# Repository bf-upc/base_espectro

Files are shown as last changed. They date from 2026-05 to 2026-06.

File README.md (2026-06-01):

# ESPectro 🎮
<p align="center">
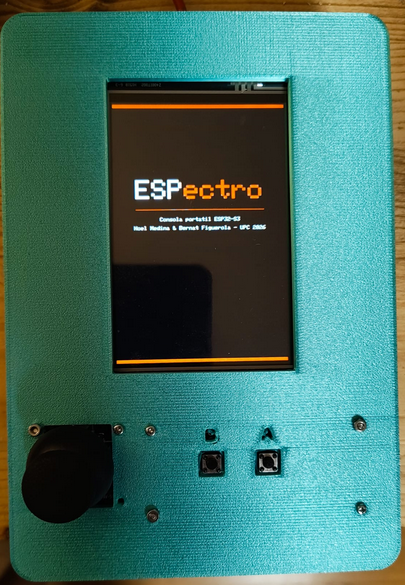
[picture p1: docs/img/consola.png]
  
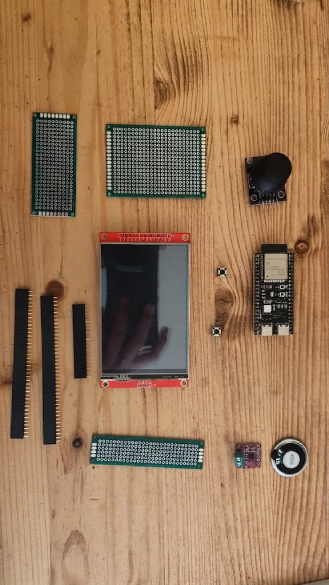
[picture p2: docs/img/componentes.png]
  
</p>

**Consola portátil de videojuegos basada en ESP32-S3**, desarrollada como proyecto final de la asignatura de Processadors Digitals (UPC, 2026).

> Noel Medina & Bernat Figuerola — ESUPC

---

## ¿Qué es ESPectro?

ESPectro es una consola portátil de videojuegos diseñada y construida desde cero. Combina hardware personalizado, firmware en C++ con FreeRTOS, conectividad WiFi, un dashboard web en tiempo real e integración con modelos de lenguaje (LLMs) mediante el protocolo MCP.

El sistema permite cargar nuevos juegos sin cables — directamente desde el navegador vía WiFi.

---

## Hardware

| Componente | Modelo |
|---|---|
| Procesador | ESP32-S3-DevKitC-1 N16R8 |
| Pantalla | TFT ILI9488 4" (SPI) |
| Joystick | HW-504 analógico |
| Audio | MAX98357A I2S + altavoz 8Ω |
| Botones | 2× táctil 6×6mm |
| Carcasa | PLA impreso en 3D — diseño propio |

### Pines de conexión

| GPIO | Función |
|---|---|
| 38 | SPI MOSI (pantalla) |
| 47 | SPI SCLK (pantalla) |
| 48 | SPI MISO (pantalla) |
| 2 | TFT DC |
| 1 | TFT CS |
| 0 | TFT RST |
| 39 | TFT BL |
| 5 | Joystick VRX |
| 4 | Joystick VRY |
| 42 | Joystick SW |
| 40 | Botón A |
| 41 | Botón B |
| 8 | I2S BCLK |
| 16 | I2S LRCLK |
| 18 | I2S DIN |

---

## Arquitectura del software

```
Arranca
  → Splash screen ESPectro
  → Menú principal
        ├─ Botón A → Juego
        └─ Botón B → Game Loader (WiFi)
```

### FreeRTOS — 3 tareas concurrentes

| Tarea | Core | Prioridad | Función |
|---|---|---|---|
| `musicTask` | 0 | 2 | Audio I2S continuo |
| `wifiTask` | 0 | 1 | Servidor web en segundo plano |
| `loop()` | 1 | — | Juego, menú, lógica |

**Sincronización:**
- `audioQueue` — Queue FreeRTOS para efectos de sonido
- `recordMutex` — Mutex para proteger acceso a NVS entre tareas

### WiFi y dashboard

El WiFi arranca automáticamente al encender la consola y se mantiene activo en segundo plano mientras se juega.

- **Red:** `ESPectro` · **Contraseña:** `gameloader`
- **Dashboard:** `http://192.168.4.1`

El dashboard muestra en tiempo real por cada juego:
- Récord máximo
- Número de partidas jugadas
- Media de puntuación
- Gráfica de barras de las últimas 10 partidas

### NVS — Persistencia

Los récords se guardan en la memoria flash no volátil (NVS) y persisten entre reinicios y entre juegos. El historial guarda las últimas 20 partidas por juego.

### Game Loader — OTA vía WiFi

Permite actualizar o cambiar el juego sin cables:

1. Pulsa **Botón B** en el menú
2. Conéctate a la red **ESPectro**
3. Abre `http://192.168.4.1` en el navegador
4. Selecciona el `.bin` y súbelo
5. La consola reinicia con el nuevo juego

### MCP — Integración con LLMs

La consola expone un servidor MCP que permite a los modelos de lenguaje consultar los datos en tiempo real.

| Endpoint | Descripción |
|---|---|
| `GET /mcp/tools` | Lista las tools disponibles |
| `GET /mcp/tools/call?tool=get_records` | Récords e historial |
| `GET /mcp/tools/call?tool=get_status` | Uptime y memoria |
| `GET /mcp/tools/call?tool=get_system_info` | Info del hardware |

---

## Juegos disponibles

| Juego | Repositorio | Descripción |
|---|---|---|
| 🏎 Road Rush | [road_rush_espectro](https://github.com/bf-upc/road_rush_espectro) | Juego de carreras — esquiva obstáculos y acelera con el joystick |
| 🟦 Tetris | [tetris_espectro](https://github.com/bf-upc/tetris_espectro) | Tetris clásico — piezas, líneas y puntuación |
| ♣️ Blackjack | [blackjack_espectro](https://github.com/bf-upc/blackjack_espectro) | Blackjack con baraja de poker y mecánica de apuestas |
| ⭕ Tres en Ratlla | [tres_en_ratlla_ESPectro](https://github.com/nm-upc/tres_en_ratlla_ESPectro) | Tres en raya contra la IA con algoritmo minimax |
| 🐸 Frogger | [frogger_ESPectro](https://github.com/nm-upc/frogger_ESPectro) | Cruza la carretera esquivando coches |
| 🐍 Snake | [snake_ESPectro](https://github.com/nm-upc/snake_ESPectro) | Snake clásico — come manzanas y crece sin chocarte |
| 🐦 Flappy Bird | [flappy_bird_ESPectro](https://github.com/nm-upc/flappy_bird_ESPectro) | Esquiva tuberías pulsando el botón A |
| 💣 Buscaminas | [buscaminas_ESPectro](https://github.com/nm-upc/buscaminas_ESPectro) | Buscaminas clásico con joystick |

---

## Estructura del repositorio

```
base_espectro/
├── README.md
├── PLANTILLA_JUEGOS/
│   ├── src/
│   │   └── main.cpp        ← plantilla para nuevos juegos
│   ├── platformio.ini
│   └── README.md           ← documentación para desarrolladores
├── mcp/
│   ├── mcp_ollama.py       ← puente Ollama ↔ ESPectro
│   ├── start_mcp_bridge.sh ← script linux
│   └── requirements.txt
├── 3D/
│   ├── front.stl           ← carcasa frontal (impresión 3D)
│   └── back.stl            ← carcasa trasera (impresión 3D)
└── docs/
    ├── memoria_tecnica.pdf
    ├── esquema_electrico.png
    └── img/
```

---

## Carcasa 3D

El diseño de la carcasa está disponible en la carpeta [`3D/`](3D/) en formato STL, listo para imprimir.

| Archivo | Descripción |
|---|---|
| `front.stl` | Parte frontal — pantalla, joystick y botones |
| `back.stl` | Parte trasera — ESP32 y altavoz |

**Parámetros de impresión recomendados:**
- Material: PLA
- Relleno: 20%
- Soportes: No necesarios
- Tornillería: M2×25 (unión frontal/trasera), M3×6 (pantalla), M2×6 (joystick)

---

## Crear un nuevo juego

Consulta [`PLANTILLA_JUEGOS/README.md`](PLANTILLA_JUEGOS/README.md) para las instrucciones completas.

Resumen:
1. Copia `PLANTILLA_JUEGOS/src/main.cpp` a tu proyecto
2. Rellena los 4 `TODO` (clave del récord, título, variables, lógica)
3. Compila con PlatformIO
4. Sube el `.bin` vía Game Loader

El juego aparece automáticamente en el dashboard sin ninguna configuración adicional.

---

## Usar el MCP con Ollama

```bash
# Instalar dependencias
pip install -r mcp/requirements.txt

# Instalar modelo necesario
ollama pull llama3.2:3b

# Parar Ollama y reiniciar forzando CPU
pkill ollama
CUDA_VISIBLE_DEVICES="" ollama serve &
sleep 3

# Ejecutar el puente
python3 mcp/mcp_ollama.py
```

Ejemplos de preguntas:
- *"¿Cuál es el récord del Road Rush?"*
- *"¿Cuántas partidas se han jugado en total?"*
- *"¿Cuánto tiempo lleva encendida la consola?"*

---

## Compilar y flashear

Requisitos: **PlatformIO** y la librería `lovyan03/LovyanGFX @ ^1.1.12`.

```bash
# Clonar un juego
git clone https://github.com/bf-upc/road_rush_espectro
cd road_rush_espectro

# Compilar y flashear
pio run --target upload

# Monitor serie
pio device monitor
```

---

## Buses y periféricos

| Bus | Periférico | Función |
|-----|---|---|
| SPI | ILI9488 | Pantalla TFT |
| I2S | MAX98357A | Audio digital |
| ADC | HW-504 | Joystick analógico |

---

## Licencia

MIT — libre para usar, modificar y distribuir.

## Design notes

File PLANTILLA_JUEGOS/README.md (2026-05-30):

# ESPectro — Template de Joc

Template per desenvolupar jocs per a la **consola portàtil ESPectro** basada en ESP32-S3.

---

## Índex

1. [Arquitectura del sistema](#arquitectura-del-sistema)
2. [Requisits](#requisits)
3. [Instruccions per a humans](#instruccions-per-a-humans)
4. [Instruccions per a LLMs](#instruccions-per-a-llms)
5. [API de hardware](#api-de-hardware)
6. [Dashboard i MCP](#dashboard-i-mcp)
7. [Exemple mínim](#exemple-mínim)
8. [Pujar el joc a la consola](#pujar-el-joc-a-la-consola)

---

## Arquitectura del sistema

```
firmware.bin = launcher + joc (tot en un sol fitxer)

Arrenca
  → Splash screen ESPectro (logo + jingle)
  → Menú principal
        │
        ├─ Botó A → runGame()  ← AQUÍ VA EL TEU JOC
        │              │
        │              └─ return → torna al menú
        │
        └─ Botó B → Game Loader (WiFi AP)
                        │
                        ├─ Dashboard amb rècords de tots els jocs
                        ├─ Puja nou .bin via navegador
                        └─ Botó A → torna al menú
```

**FreeRTOS — 3 tasques concurrents:**

| Tasca | Core | Prioritat | Funció |
|---|---|---|---|
| `musicTask` | 0 | 2 | Àudio I2S continu |
| `wifiTask` | 0 | 1 | Servidor web en segon pla |
| `loop()` | 1 | — | Joc, menú, lògica |

**Sincronització:**
- `audioQueue` (Queue) — efectes de so des del joc a `musicTask`
- `recordMutex` (Mutex) — protegeix NVS entre `wifiTask` i `runGame()`

**WiFi sempre actiu** des de l'arrencada — el dashboard és accessible a `http://192.168.4.1` en tot moment, fins i tot mentre jugues.

---

## Requisits

**Hardware:**
- ESP32-S3-DevKitC-1 N16R8
- Pantalla TFT ILI9488 4" (SPI)
- Joystick analògic HW-504
- 2 botons tactils 6×6mm
- Amplificador I2S MAX98357A + altavoz 8Ω

**Software:**
- PlatformIO
- Llibreria LovyanGFX `^1.1.12`

**`platformio.ini` mínim:**
```ini
[env:consola]
platform    = espressif32
board       = rymcu-esp32-s3-devkitc-1
framework   = arduino
monitor_speed = 115200
lib_deps =
    lovyan03/LovyanGFX @ ^1.1.12
```

---

## Instruccions per a humans

### Pas 1 — Copia la template
Copia `template_joc.cpp` al teu projecte PlatformIO com a `src/main.cpp`.

### Pas 2 — Omple els TODO

Cerca les línies marcades amb `// TODO:` al fitxer. Són exactament 4:

#### 2.1 Clau del rècord
```cpp
#define RECORD_KEY "nom_joc"  // TODO: canvia això!
```
Posa el nom del teu joc en minúscules i sense espais. Exemple:
```cpp
#define RECORD_KEY "snake"
```
Aquesta clau s'usa per guardar el rècord a la NVS i apareix automàticament al dashboard.

#### 2.2 Títol del menú
```cpp
const char* linia1 = "NOM";   // TODO: primera línia del títol
const char* linia2 = "JOC";   // TODO: segona línia del títol
```

#### 2.3 Variables globals del joc
```cpp
// TODO: VARIABLES GLOBALS DEL JOC
```

#### 2.4 Lògica del joc dins de `runGame()`
```cpp
void runGame() {
    // TODO: implementa el teu joc aquí
}
```

### Pas 3 — Guarda el rècord correctament
Usa el mutex per protegir l'accés a la NVS:
```cpp
if (xSemaphoreTake(recordMutex, pdMS_TO_TICKS(200)) == pdTRUE) {
    saveRecord(score);  // guarda SEMPRE, no només si és rècord
    xSemaphoreGive(recordMutex);
}
```
`saveRecord()` ja gestiona internament si ha de actualitzar el màxim o no.

### Pas 4 — Compila i puja
```
pio run --target upload
```
O via Game Loader (veure [Pujar el joc a la consola](#pujar-el-joc-a-la-consola)).

---

## Instruccions per a LLMs

> Aquesta secció explica com generar un joc complet per a la consola ESPectro a partir de la template.

### Regles obligatòries

1. **NO modificar** cap secció marcada com `// NO MODIFICAR`. Inclou: configuració de pantalla, pins, WiFi, FreeRTOS, Game Loader, menú principal, `setup()`, `loop()`.

2. **Sempre fer `return`** al final de `runGame()` per tornar al menú. Mai usar `while(true)` sense condició de sortida.

3. **`RECORD_KEY`** ha de ser una string única per joc, en minúscules, sense espais ni caràcters especials. Exemples vàlids: `"snake"`, `"pong"`, `"tetris_v2"`.

4. **No usar `delay()` llargs** dins del bucle de joc. Usar `millis()` per controlar el timing.

5. **La pantalla és de 320×480 píxels**, orientació vertical (portrait), rotació 2. L'origen (0,0) és a la cantonada superior esquerra.

6. **L'àudio és síncron** — `playTone()` bloqueja l'execució. Usar-lo amb moderació o implementar una `musicTask` FreeRTOS separada.

7. **Guardar el rècord sempre** al final de la partida (no només si és millor), protegint amb `recordMutex`:
```cpp
if (xSemaphoreTake(recordMutex, pdMS_TO_TICKS(200)) == pdTRUE) {
    saveRecord(score);
    xSemaphoreGive(recordMutex);
}
```

8. **El joc s'auto-registra al dashboard** — en cridar `saveRecord()` per primera vegada, el joc apareix automàticament al dashboard web sense cap configuració addicional.

### Estructura que ha de tenir `runGame()`

```cpp
void runGame() {
    // 1. Carregar rècord
    int bestScore = loadRecord();

    // 2. Inicialitzar variables del joc
    int score = 0;

    // 3. Dibuixar pantalla inicial
    tft.fillScreen(TFT_BLACK);

    // 4. Bucle principal
    unsigned long lastFrame = millis();
    while (true) {

        // Control de framerate (recomanat 20ms = ~50fps)
        if (millis() - lastFrame < 20) continue;
        lastFrame = millis();

        // 5. Llegir controls
        int rawX = analogRead(JOY_X_PIN);
        int rawY = analogRead(JOY_Y_PIN);
        bool btnA = (digitalRead(BTN_A_PIN) == LOW);

        // 6. Lògica del joc
        // ...

        // 7. Dibuixar
        tft.startWrite();
        // ...
        tft.endWrite();

        // 8. Fi de joc -> guardar rècord i tornar al menú
        if (gameOver) {
            if (xSemaphoreTake(recordMutex, pdMS_TO_TICKS(200)) == pdTRUE) {
                saveRecord(score);
                xSemaphoreGive(recordMutex);
            }
            // Mostrar pantalla game over, esperar botó...
            return;  // <- OBLIGATORI per tornar al menú
        }
    }
}
```

### Bones pràctiques de dibuix

- Usar `tft.startWrite()` / `tft.endWrite()` per agrupar operacions.
- **No fer `fillScreen()` cada frame** — esborrar només les zones que canvien.
- Per esborrar un sprite: `tft.fillRect(x, y, w, h, COLOR_FONS)` a la posició anterior.

### Freqüències musicals (rang recomanat: 200-600Hz)

| Nota | Freqüència |
|---|---|
| A3 | 220.0 Hz  |
| C4 | 261.6 Hz  |
| D4 | 293.7 Hz  |
| E4 | 329.6 Hz  |
| G4 | 392.0 Hz  |
| A4 | 440.0 Hz  |
| C5 | 523.3 Hz  |
| D5 | 587.3 Hz  |

Volum recomanat: `0.07f` música de fons, `0.10f` efectes. Mai superar `0.20f`.

---

## API de hardware

### Pantalla

```cpp
SCREEN_W = 320   // amplada en píxels
SCREEN_H = 480   // alçada en píxels

tft.fillScreen(color);
tft.fillRect(x, y, w, h, color);
tft.drawRect(x, y, w, h, color);
tft.fillCircle(x, y, r, color);
tft.drawLine(x0, y0, x1, y1, color);
tft.drawFastHLine(x, y, w, color);
tft.drawFastVLine(x, y, h, color);

tft.setTextSize(n);          // 1=petit, 2=mitjà, 3=gran, 4=molt gran
tft.setTextColor(color, bg);
tft.setCursor(x, y);
tft.print("text");
tft.printf("valor: %d", n);
int w = tft.textWidth("text");

// Colors predefinits
TFT_BLACK, TFT_WHITE, TFT_RED, TFT_GREEN, TFT_BLUE
TFT_YELLOW, TFT_CYAN, TFT_MAGENTA, TFT_DARKGREY

// Color personalitzat
uint16_t color = tft.color565(r, g, b);  // r,g,b: 0-255

// Agrupar operacions (imprescindible per bon rendiment)
tft.startWrite();
// ...
tft.endWrite();
```

### Controls

```cpp
// Joystick analògic (0-4095, centre ~2048)
int rawX = analogRead(JOY_X_PIN);   // esquerra < 1748 / dreta > 2348
int rawY = analogRead(JOY_Y_PIN);   // amunt < 1748 / avall > 2348
bool joyBtn = (digitalRead(JOY_SW_PIN) == LOW);

// Botons (LOW = premut)
bool btnA = (digitalRead(BTN_A_PIN) == LOW);
bool btnB = (digitalRead(BTN_B_PIN) == LOW);

// Obtenir direcció (-1, 0, 1)
int dirX = (rawX < 1748) ? -1 : (rawX > 2348) ? 1 : 0;
int dirY = (rawY < 1748) ? -1 : (rawY > 2348) ? 1 : 0;
```

### Àudio

```cpp
// To sinusoïdal (síncron — bloqueja l'execució)
playTone(float freq, int durationMs, float volume);

// Silenci
playSilence(int durationMs);

// Exemple
playTone(440.0f, 50, 0.10f);          // La4, 50ms
playTone(261.6f, 100, 0.10f);         // C4
playSilence(20);
playTone(392.0f, 200, 0.12f);         // G4
```

### Rècords (NVS — persisteix entre reinicis i entre jocs)

```cpp
// Guardar rècord — sempre protegir amb mutex
if (xSemaphoreTake(recordMutex, pdMS_TO_TICKS(200)) == pdTRUE) {
    saveRecord(score);   // guarda a l'historial i actualitza el màxim si cal
    xSemaphoreGive(recordMutex);
}

// Llegir rècord màxim
int best = loadRecord();
```

L'historial guarda les **últimes 20 partides** per joc. Apareix automàticament al dashboard web.

---

## Dashboard i MCP

### Dashboard web

Accessible a `http://192.168.4.1` mentre la consola està encesa (WiFi sempre actiu).

Mostra per cada joc:
- Rècord màxim
- Nombre de partides jugades
- Mitjana de puntuació
- Darrera puntuació
- Gràfica de barres de les últimes 10 partides

Els jocs apareixen automàticament quan es guarda el primer rècord. No cal configurar res.

### Endpoints MCP

La consola exposa un servidor MCP per integrar-se amb LLMs (Ollama, etc.):

| Endpoint | Descripció |
|---|---|
| `GET /mcp/tools` | Llista les tools disponibles |
| `GET /mcp/tools/call?tool=get_records` | Rècords i historial de tots els jocs |
| `GET /mcp/tools/call?tool=get_status` | Uptime, memòria lliure, IP, versió |
| `GET /mcp/tools/call?tool=get_system_info` | CPU, flash, PSRAM, SDK |

### Ús amb Ollama

```bash
# Instal·lar dependències
pip install ollama requests

# Aturar Ollama i reiniciar forçant CPU (recomanat amb GPU petita)
pkill ollama
CUDA_VISIBLE_DEVICES="" ollama serve &
sleep 3

# Executar el pont MCP
python3 espectro_mcp.py
```

Exemples de preguntes:
- "Quin és el rècord del Road Rush?"
- "Quantes partides s'han jugat en total?"
- "Quant temps porta encesa la consola?"
- "Quanta memòria lliure té l'ESP32?"

---

## Exemple mínim

```cpp
// Variables globals:
int playerX, playerY, score;

// runGame():
void runGame() {
    int bestScore = loadRecord();
    playerX = SCREEN_W / 2;
    playerY = SCREEN_H / 2;
    score = 0;

    tft.fillScreen(TFT_BLACK);

    unsigned long lastFrame = millis();
    unsigned long lastScore = millis();

    while (true) {
        if (millis() - lastFrame < 20) continue;
        lastFrame = millis();

        if (millis() - lastScore > 1000) {
            lastScore = millis();
            score++;
        }

        int rawX = analogRead(JOY_X_PIN);
        int rawY = analogRead(JOY_Y_PIN);
        int dirX = (rawX < 1748) ? -1 : (rawX > 2348) ? 1 : 0;
        int dirY = (rawY < 1748) ? -1 : (rawY > 2348) ? 1 : 0;

        tft.fillRect(playerX-10, playerY-10, 20, 20, TFT_BLACK);
        playerX = constrain(playerX + dirX * 4, 10, SCREEN_W-10);
        playerY = constrain(playerY + dirY * 4, 10, SCREEN_H-10);

        tft.startWrite();
        tft.fillRect(playerX-10, playerY-10, 20, 20, TFT_GREEN);
        tft.setTextColor(TFT_WHITE, TFT_BLACK);
        tft.setTextSize(2);
        tft.setCursor(10, 10);
        tft.printf("Pts: %d  ", score);
        tft.endWrite();

        if (digitalRead(BTN_B_PIN) == LOW) {
            if (xSemaphoreTake(recordMutex, pdMS_TO_TICKS(200)) == pdTRUE) {
                saveRecord(score);
                xSemaphoreGive(recordMutex);
            }
            return;
        }
    }
}
```

---

## Pujar el joc a la consola

1. Compila: `pio run`
2. El binari és a: `.pio/build/rymcu-esp32-s3-devkitc-1/firmware.bin`
3. Prem el **botó B** al menú per entrar al Game Loader
4. Connecta't a la xarxa WiFi **ESPectro** (contrasenya: **gameloader**)
5. Obre el navegador a **http://192.168.4.1**
6. Selecciona el `firmware.bin` i prem "Pujar joc"
7. La consola reinicia amb el nou joc

---

## Pins de referència

| GPIO | Funció |
|---|---|
| 38 | SPI MOSI (pantalla) |
| 47 | SPI SCLK (pantalla) |
| 48 | SPI MISO (pantalla) |
| 2 | TFT DC |
| 1 | TFT CS |
| 0 | TFT RST |
| 39 | TFT BL (retroil·luminació) |
| 5 | Joystick VRX (eix X) |
| 4 | Joystick VRY (eix Y) |
| 42 | Joystick SW (botó) |
| 40 | Botó A |
| 41 | Botó B |
| 8 | I2S BCLK |
| 16 | I2S LRCLK |
| 18 | I2S DIN |

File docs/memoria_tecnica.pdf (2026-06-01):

ESPectro — Memoria Tecnica | Medina & Figuerola — UPC 2026

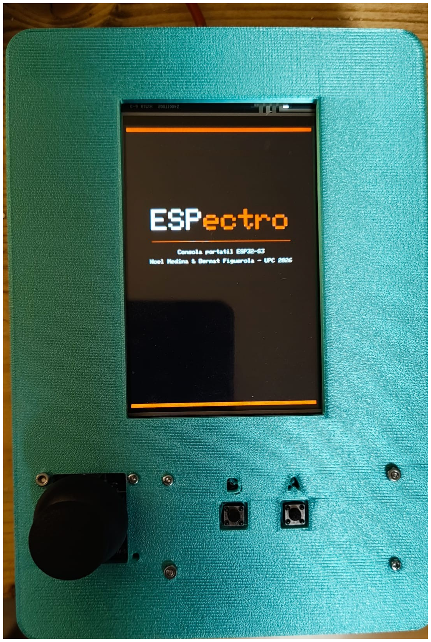
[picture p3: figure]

Processadors Digitals | Pag. 1

# ESPectro

Consola portatil de videojuegos basada en ESP32-S3

## Memoria Tecnica

Noel Medina & Bernat Figuerola Processadors Digitals - ESEIAAT, 2026

## 1. Introduccion

### 1.1 Motivacion

ESPectro nace con el objetivo de disenar y construir una consola portatil de videojuegos completamente funcional utilizando el microcontrolador ESP32-S3 como procesador principal. El proyecto integra hardware personalizado, firmware en tiempo real con FreeRTOS, conectividad WiFi y un sistema de actualizacion de firmware OTA sin necesidad de cables.
A diferencia de las consolas comerciales, ESPectro esta disenada para ser extensible: cualquier desarrollador puede crear nuevos juegos utilizando la template proporcionada y cargarlos en la consola directamente desde el navegador.

### 1.2 Objetivos

- Disenar e implementar una consola portatil con ESP32-S3 como procesador principal.
- Integrar pantalla TFT, joystick analogico, botones y sistema de audio I2S.
- Implementar FreeRTOS con multiples tareas y mecanismos de sincronizacion.
- Desarrollar un sistema de actualizacion OTA via WiFi con interfaz web.
- Implementar un servidor MCP para integracion con modelos de lenguaje (LLMs).
- Disenar e imprimir en 3D una carcasa para la consola.
- Crear una template reutilizable para el desarrollo de nuevos juegos.

## 2. Hardware

### 2.1 Componentes

Componente | Modelo | Interfaz | Funcion
Procesador | ESP32-S3-DevKitC-1 N16R8 | — | CPU principal, WiFi, BLE
Pantalla | TFT ILI9488 4" | SPI | Visualizacion del juego
Joystick | HW-504 analogico | ADC | Control de movimiento
Audio | MAX98357A + altavoz 8 ohm | I2S | Efectos de sonido y musica
Botones | 2x tactil 6x6mm | GPIO | Boton A y Boton B
Carcasa | PLA impreso en 3D | — | Estructura mecanica
Componentes

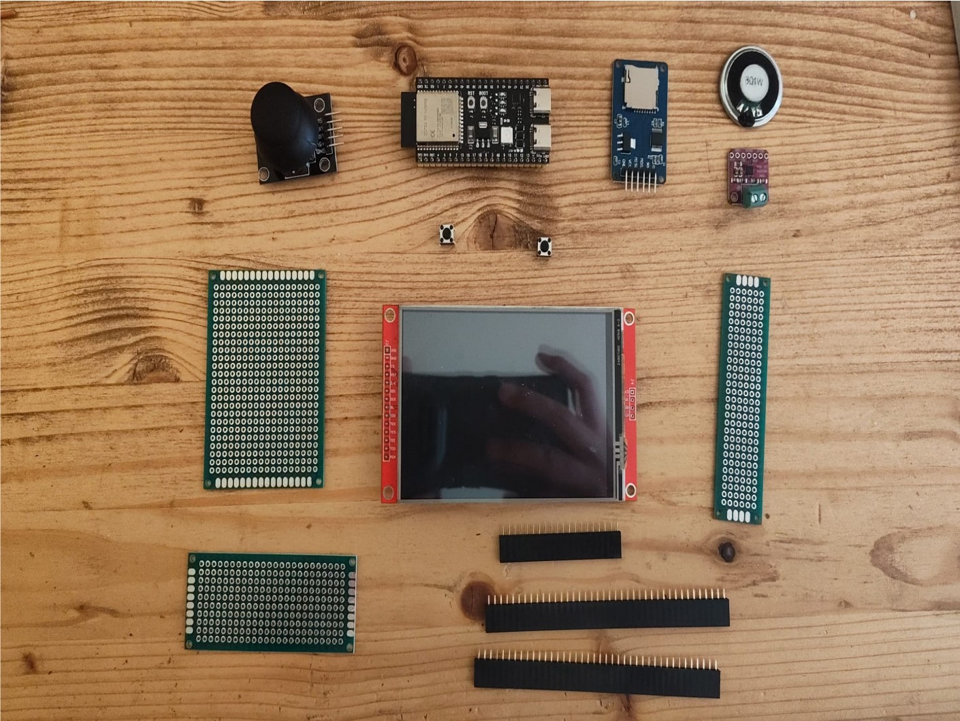
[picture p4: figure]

Inicialmente ibamos a usar un lector de microSD, pero nos llegaron defectuosos y decidimos no usarlo.

### 2.2 Mapa de pines

GPIO | Senal | Bus | Componente
38 | MOSI | SPI | Pantalla ILI9488
47 | SCLK | SPI | Pantalla ILI9488
48 | MISO | SPI | Pantalla ILI9488
2 | DC | SPI | Pantalla ILI9488
1 | CS | SPI | Pantalla ILI9488
0 | RST | GPIO | Pantalla ILI9488
39 | BL | PWM | Retroiluminacion pantalla
5 | VRX | ADC1 | Joystick eje X
4 | VRY | ADC1 | Joystick eje Y
42 | SW | GPIO | Boton joystick
40 | BTN_A | GPIO | Boton A
41 | BTN_B | GPIO | Boton B
8 | BCLK | I2S | MAX98357A
16 | LRCLK | I2S | MAX98357A
18 | DIN | I2S | MAX98357A

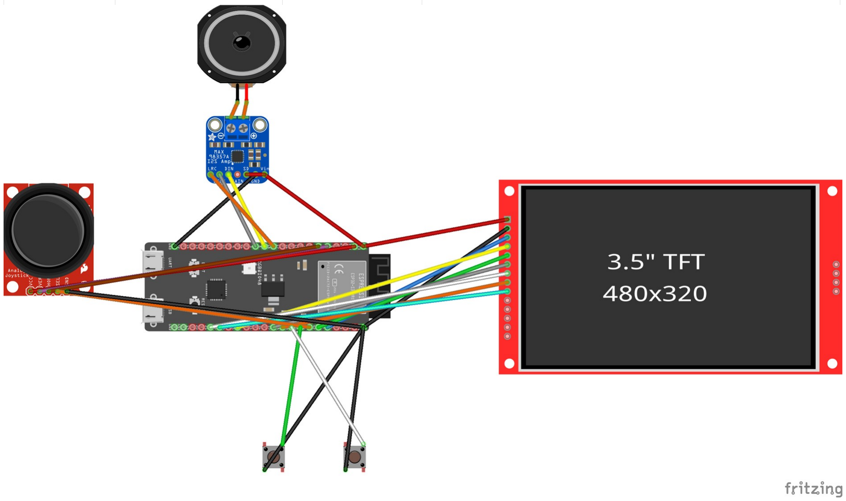
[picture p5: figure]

Diagrama hecho con fritzing

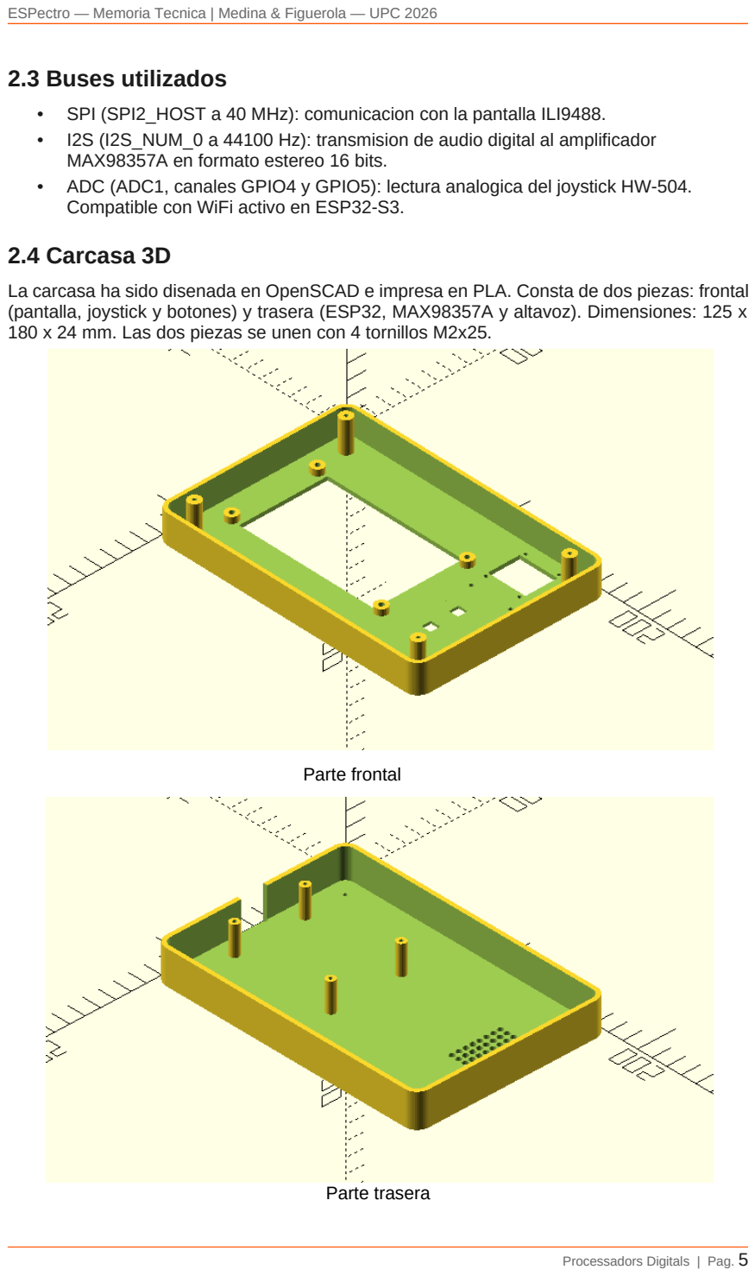
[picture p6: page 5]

### 2.3 Buses utilizados

- SPI (SPI2_HOST a 40 MHz): comunicacion con la pantalla ILI9488.
- I2S (I2S_NUM_0 a 44100 Hz): transmision de audio digital al amplificador MAX98357A en formato estereo 16 bits.
- ADC (ADC1, canales GPIO4 y GPIO5): lectura analogica del joystick HW-504. Compatible con WiFi activo en ESP32-S3.

### 2.4 Carcasa 3D

La carcasa ha sido disenada en OpenSCAD e impresa en PLA. Consta de dos piezas: frontal (pantalla, joystick y botones) y trasera (ESP32, MAX98357A y altavoz). Dimensiones: 125 x 180 x 24 mm. Las dos piezas se unen con 4 tornillos M2x25.

Parte frontal

Parte trasera

## 3. Software

### 3.1 Arquitectura general

El firmware es un binario unico que incluye el launcher y el juego. Al arrancar muestra la splash screen de ESPectro y accede al menu principal, desde donde el usuario puede jugar o acceder al Game Loader para cargar un nuevo juego.

Modulo | Descripcion
Splash screen | Logo ESPectro con jingle musical al arrancar
Menu principal | Muestra el record y las opciones de jugar o cargar
Juego | Logica del juego actual (Road Rush / Tetris)
Game Loader | Servidor web para subir nuevos .bin via WiFi
Dashboard | Estadisticas de todos los juegos en tiempo real
MCP Server | Endpoints para integracion con LLMs via Ollama
NVS | Persistencia de records e historial de partidas

### 3.2 FreeRTOS - Multitarea

Tarea | Core | Prioridad | Funcion
musicTask | 0 | 2 | Reproduce audio I2S de forma continua
wifiTask | 0 | 1 | Gestiona el servidor web en segundo plano
loop() | 1 | — | Logica del juego, menu y controles

Mecanismos de sincronizacion
- audioQueue (Queue): envia eventos de audio desde el juego (core 1) a musicTask (core 0) sin bloquear la ejecucion del juego.
- recordMutex (Mutex): protege el acceso a la NVS entre wifiTask (sirve records al dashboard) y runGame() (escribe records al terminar partida).

### 3.3 WiFi y dashboard

El WiFi arranca en modo Access Point automaticamente al encender la consola. Red: ESPectro, contrasena: gameloader, IP: 192.168.4.1. El dashboard web muestra todos los juegos registrados con su record maximo, numero de partidas, media de puntuacion y grafica de las ultimas 10 partidas. Se actualiza cada 10 segundos.

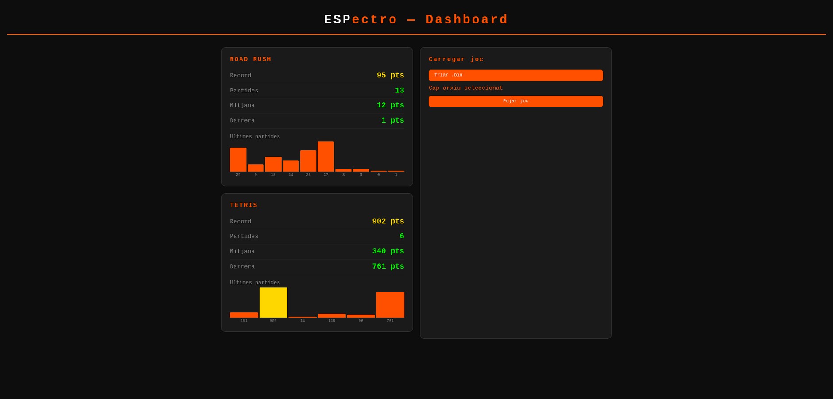
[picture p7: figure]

Dashboard ESPectro

### 3.4 OTA - Game Loader

Permite actualizar el firmware sin cables. El usuario pulsa Boton B, se conecta a la red ESPectro, abre http://192.168.4.1, selecciona el .bin compilado con PlatformIO y lo sube. El ESP32 lo escribe en flash con Update.h y reinicia automaticamente.

### 3.5 Persistencia - NVS

Clave NVS | Tipo | Contenido
road_rush | int32 | Record maximo del juego Road Rush
road_rush_h | string | JSON con las ultimas 20 puntuaciones
game_list | string | CSV con los juegos registrados

### 3.6 Servidor MCP

Endpoint | Descripcion
GET /mcp/tools | Lista las tools disponibles
GET /mcp/tools/call?tool=get_records | Records e historial de todos los juegos
GET /mcp/tools/call?tool=get_status | Uptime, memoria libre, IP y version
GET /mcp/tools/call?tool=get_system_info | CPU, flash, PSRAM y version SDK

Se ha desarrollado un script Python (mcp/mcp_ollama.py) que actua como puente entre Ollama y los endpoints MCP, inyectando los datos de la consola como contexto al modelo de lenguaje.

### 3.7 Template para nuevos juegos

Se ha desarrollado una template (PLANTILLA_JUEGO/src/main.cpp) que integra todo el sistema. Para crear un nuevo juego solo hay que rellenar cuatro secciones TODO: RECORD_KEY, titulo del menu, variables globales y la funcion runGame(). Al guardar el primer record, el juego aparece automaticamente en el dashboard.

## 4. Juegos desarrollados

### 4.1 Road Rush

Juego de carreras en el que el jugador controla un coche que debe esquivar obstaculos. El joystick controla el movimiento lateral y la velocidad. La puntuacion aumenta con cada obstaculo superado. Incluye musica ambient en loop y efectos de sonido via FreeRTOS.

### 4.2 Tetris

Implementacion del Tetris clasico con las siete piezas estandar. El joystick controla el movimiento lateral y la caida rapida. El Boton A rota la pieza. Puntuacion de 100 puntos por linea eliminada con bonus por multiples lineas simultaneas.

### 4.3 Blackjack

Implementación del clásico juego de cartas Blackjack con baraja de póker estándar. El jugador compite contra la banca con el objetivo de acercarse a 21 sin pasarse. El Botón A pide carta (Hit) y el Botón B se planta (Stand). Incluye mecánica de apuestas y gestión de bankroll persistente.

### 4.4 Tres en Ratlla

Implementación del tres en raya contra una inteligencia artificial basada en el algoritmo Minimax, que garantiza el juego óptimo por parte de la máquina. El joystick mueve el cursor por el tablero 3×3 y el Botón A coloca la pieza. La puntuación registra el número de victorias acumuladas.

### 4.5 Frogger

Recreación del arcade clásico Frogger. El jugador controla una rana que debe cruzar una carretera con coches en movimiento. El joystick controla el movimiento en las cuatro direcciones. La puntuación aumenta con cada cruce completado y la dificultad se incrementa progresivamente.

### 4.6 Snake

Implementación del Snake clásico. El jugador controla una serpiente que crece al comer manzanas y debe evitar chocar contra las paredes o contra su propio cuerpo. El joystick controla la dirección. La puntuación aumenta con cada manzana comida.

### 4.7 Flappy Bird

Recreación del popular juego Flappy Bird. El jugador controla un pájaro que debe esquivar tuberías pulsando el Botón A para aletear. La física de gravedad hace que el pájaro caiga continuamente. La puntuación aumenta con cada tubería superada.

### 4.8 Buscaminas

Implementación del Buscaminas clásico con tablero configurable. El joystick mueve el cursor por el tablero y el Botón A revela una casilla. El Botón B marca o desmarca una mina sospechosa con bandera. La puntuación se basa en el tiempo empleado en completar el tablero.

## 5. Resultados

### 5.1 Requisitos cumplidos

Requisito | Estado | Implementacion
ESP32 como procesador | SI | ESP32-S3-DevKitC-1 N16R8
Conectividad WiFi | SI | AP siempre activo (ESPectro)
OTA operativa | SI | HTTP POST con Update.h
Display | SI | TFT ILI9488 4" via SPI
Sensores (ADC/SPI) | SI | Joystick ADC1, pantalla SPI
FreeRTOS 2+ tareas | SI | 3 tareas: music, wifi, loop
Sincronizacion RTOS | SI | Queue + Mutex
2+ buses distintos | SI | SPI + I2S + ADC
PlatformIO reproducible | SI | platformio.ini documentado
MCP (innovacion) | SI | 4 endpoints + puente Ollama

### 5.2 Rendimiento

- Framerate del juego: ~50 fps (frame cada 20 ms en core 1).
- Latencia audio: < 10 ms gracias a la arquitectura de colas FreeRTOS.
- Tiempo de arranque: ~3 segundos hasta el menu principal.
- Tiempo de carga OTA: ~30 segundos para un firmware de 1.2 MB.
- Memoria heap libre en juego: ~120 KB de los 320 KB disponibles.

## 6. Conclusiones

### 6.1 Logros

El proyecto ESPectro ha cumplido todos los requisitos tecnicos de la asignatura e incorpora elementos innovadores como el servidor MCP y la integracion con modelos de lenguaje. La arquitectura modular basada en la template permite extender el sistema con nuevos juegos de forma sencilla, lo que ha quedado demostrado con el desarrollo de dos juegos completamente funcionales.

### 6.2 Dificultades encontradas

- Compatibilidad entre LovyanGFX y algunos headers de ESP-IDF: resuelto usando nvs_flash.h directamente.
- Módulo de microSD defectuoso / tarjetas microSD defectuosas; descartamos el uso del módulo.
- Inestabilidad de la pantalla en el arranque sin reset hardware: resuelto conectando RST al GPIO0.
- Saturacion del audio con playTone() sincrono: resuelto mediante cola FreeRTOS (audioQueue).
- Limitaciones de VRAM de la GPU en el PC para Ollama: resuelto forzando ejecucion en CPU.

### 6.3 Trabajo futuro

- Anadir autenticacion al Game Loader para mayor seguridad.
- Soporte para multiples usuarios en el dashboard.
- Ampliar el servidor MCP con una tool de control remoto del juego.
- Publicar la template como libreria PlatformIO.

## 7. Referencias

- Espressif Systems. ESP32-S3 Technical Reference Manual. https://www.espressif.com
- LovyanGFX. Documentacion oficial. https://github.com/lovyan03/LovyanGFX
- Anthropic. Model Context Protocol (MCP). https://modelcontextprotocol.io
- FreeRTOS. Reference Manual. https://www.freertos.org
- PlatformIO. Documentacion ESP32. https://docs.platformio.org
- Ollama. Documentacion oficial. https://ollama.com

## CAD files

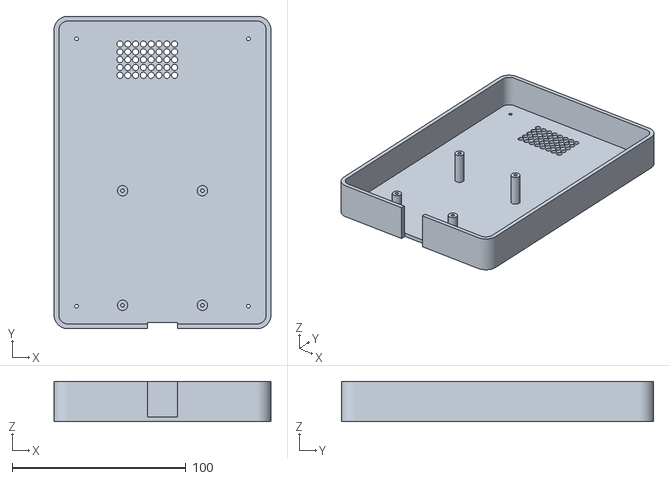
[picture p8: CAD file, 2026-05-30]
3D/back.stl
125.0 x 180.0 x 23.1

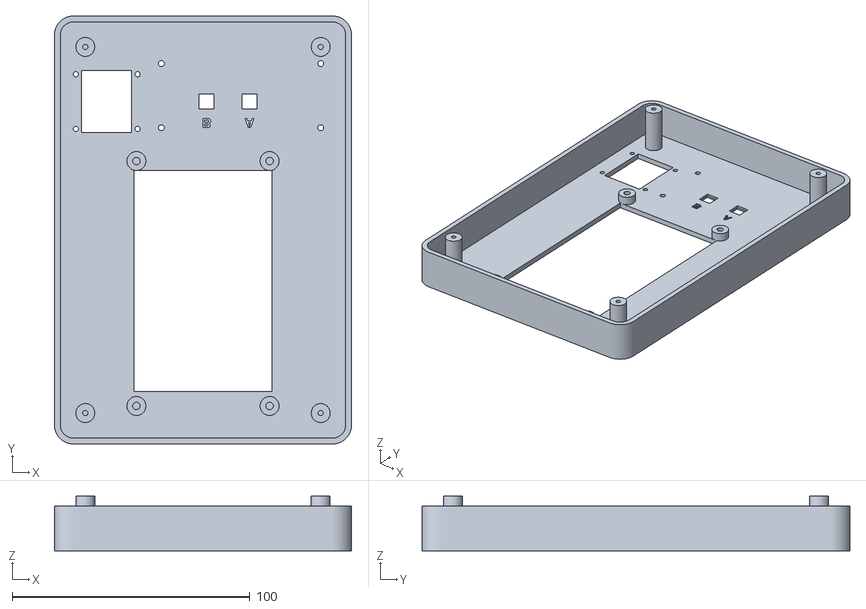
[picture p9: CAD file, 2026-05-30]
3D/front.stl
125.0 x 180.0 x 23.0

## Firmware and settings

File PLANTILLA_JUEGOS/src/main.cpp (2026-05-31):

// ============================================================
//  TEMPLATE JOC — Consola ESPectro (ESP32-S3)
//  Copia aquest fitxer i omple les seccions marcades amb TODO
//
//  INSTRUCCIONS:
//  1. Copia aquest fitxer al teu projecte PlatformIO
//  2. Omple les seccions marcades amb TODO
//  3. Compila i puja el .bin via Game Loader
//
//  NOTES IMPORTANTS:
//  - NO canviïs les seccions marcades com NO MODIFICAR
//  - El WiFi arrenca automàticament en segon pla (FreeRTOS)
//  - El dashboard és accessible a http://192.168.4.1 sempre
//  - Usa saveRecord(score) per guardar puntuació
//  - runGame() ha de fer return per tornar al menú
// ============================================================

#include <Arduino.h>
#include <SPI.h>
#include <LovyanGFX.hpp>
#include <driver/i2s.h>
#include <WiFi.h>
#include <WebServer.h>
#include <Update.h>
#include <nvs_flash.h>
#include <nvs.h>

// ============================================================
//  PANTALLA — NO MODIFICAR
// ============================================================
class LGFX : public lgfx::LGFX_Device {
    lgfx::Bus_SPI       _bus;
    lgfx::Panel_ILI9488 _panel;
    lgfx::Light_PWM     _light;
public:
    LGFX() {
        { auto cfg = _bus.config();
          cfg.spi_host   = SPI2_HOST;
          cfg.spi_mode   = 0;
          cfg.freq_write = 40000000;
          cfg.pin_sclk   = 47;
          cfg.pin_mosi   = 38;
          cfg.pin_miso   = 48;
          cfg.pin_dc     = 2;
          _bus.config(cfg);
          _panel.setBus(&_bus); }
        { auto cfg = _panel.config();
          cfg.pin_cs   = 1;
          cfg.pin_rst  = 0;
          cfg.pin_busy = -1;
          cfg.memory_width  = 320;
          cfg.memory_height = 480;
          cfg.panel_width   = 320;
          cfg.panel_height  = 480;
          cfg.invert    = false;
          cfg.rgb_order = false;
          _panel.config(cfg); }
        { auto cfg = _light.config();
          cfg.pin_bl      = 39;
          cfg.invert      = false;
          cfg.freq        = 44100;
          cfg.pwm_channel = 0;
          _light.config(cfg);
          _panel.setLight(&_light); }
        setPanel(&_panel);
    }
};

LGFX tft;

// ============================================================
//  PINS — NO MODIFICAR
// ============================================================
#define JOY_X_PIN  5
#define JOY_Y_PIN  4
#define JOY_SW_PIN 42
#define BTN_A_PIN  40
#define BTN_B_PIN  41

#define SCREEN_W 320
#define SCREEN_H 480

// ============================================================
//  I2S AUDIO — NO MODIFICAR
// ============================================================
#define I2S_BCLK    8
#define I2S_LRCLK  16
#define I2S_DIN    18
#define SAMPLE_RATE 44100
#define I2S_PORT    I2S_NUM_0

void audioInit() {
    i2s_config_t cfg = {
        .mode                 = (i2s_mode_t)(I2S_MODE_MASTER | I2S_MODE_TX),
        .sample_rate          = SAMPLE_RATE,
        .bits_per_sample      = I2S_BITS_PER_SAMPLE_16BIT,
        .channel_format       = I2S_CHANNEL_FMT_RIGHT_LEFT,
        .communication_format = I2S_COMM_FORMAT_STAND_I2S,
        .intr_alloc_flags     = ESP_INTR_FLAG_LEVEL1,
        .dma_buf_count        = 8,
        .dma_buf_len          = 512,
        .use_apll             = false,
        .tx_desc_auto_clear   = true,
    };
    i2s_driver_install(I2S_PORT, &cfg, 0, NULL);
    i2s_pin_config_t pins = {
        .bck_io_num   = I2S_BCLK,
        .ws_io_num    = I2S_LRCLK,
        .data_out_num = I2S_DIN,
        .data_in_num  = I2S_PIN_NO_CHANGE,
    };
    i2s_set_pin(I2S_PORT, &pins);
    i2s_zero_dma_buffer(I2S_PORT);
}

// To sinusoïdal — freq(Hz), durada(ms), volum(0.0-0.2)
void playTone(float freq, int durationMs, float volume = 0.1f) {
    const int bufSize = 256;
    int16_t buf[bufSize * 2];
    const int samples = SAMPLE_RATE * durationMs / 1000;
    int written = 0;
    while (written < samples) {
        int chunk = min(bufSize, samples - written);
        for (int i = 0; i < chunk; i++) {
            float t   = (float)(written + i) / SAMPLE_RATE;
            int16_t v = (int16_t)(sinf(2.0f * M_PI * freq * t) * 32767.0f * volume);
            buf[i*2] = v; buf[i*2+1] = v;
        }
        size_t bw;
        i2s_write(I2S_PORT, buf, chunk * 4, &bw, portMAX_DELAY);
        written += chunk;
    }
}

void playSilence(int durationMs) {
    int16_t buf[512] = {0};
    const int samples = SAMPLE_RATE * durationMs / 1000;
    int written = 0;
    while (written < samples) {
        int chunk = min(256, samples - written);
        size_t bw;
        i2s_write(I2S_PORT, buf, chunk * 4, &bw, portMAX_DELAY);
        written += chunk;
    }
}

// ============================================================
//  SPLASH SCREEN — NO MODIFICAR
// ============================================================
void showSplash() {
    tft.fillScreen(TFT_BLACK);
    const uint16_t TARONJA = tft.color565(255, 80, 0);
    tft.fillRect(0, 0, SCREEN_W, 6, TARONJA);
    tft.setTextSize(5);
    int y_titol = 140;
    tft.setTextColor(TFT_WHITE, TFT_BLACK);
    tft.setCursor(SCREEN_W/2 - tft.textWidth("ESPectro")/2, y_titol);
    tft.print("ESP");
    tft.setTextColor(TARONJA, TFT_BLACK);
    tft.print("ectro");
    tft.drawFastHLine(40, y_titol+55, SCREEN_W-80, TARONJA);
    tft.setTextSize(1);
    tft.setTextColor(TFT_WHITE, TFT_BLACK);
    const char* slogan = "Consola portatil ESP32-S3";
    tft.setCursor(SCREEN_W/2 - tft.textWidth(slogan)/2, y_titol+70);
    tft.print(slogan);
    const char* autors = "Noel Medina & Bernat Figuerola - UPC 2026";
    tft.setCursor(SCREEN_W/2 - tft.textWidth(autors)/2, y_titol+86);
    tft.print(autors);
    tft.fillRect(0, SCREEN_H-6, SCREEN_W, 6, TARONJA);
    playTone(220.0f, 120, 0.15f); playSilence(30);
    playTone(277.2f, 120, 0.15f); playSilence(30);
    playTone(329.6f, 120, 0.15f);
    delay(500);
}

// ============================================================
//  FREERTOS — NO MODIFICAR
// ============================================================
// Sincronització:
//   audioQueue  (Queue) — efectes de so des del joc a la tasca música
//   recordMutex (Mutex) — protegeix NVS entre wifiTask i runGame()
SemaphoreHandle_t recordMutex;
volatile bool     wifiActiu = false;

// ── WiFi / Game Loader ────────────────────────────────────────
#define AP_SSID "ESPectro"
#define AP_PASS "gameloader"
#define AP_IP   "192.168.4.1"

#define MAX_HISTORY 20

// ── Clau del rècord — TODO: canvia pel nom del teu joc ───────
#define RECORD_KEY "nom_joc"  // TODO ex: "snake", "pong", "tetris"

// ============================================================
//  RECORDS NVS — NO MODIFICAR
// ============================================================
int loadRecord() {
    nvs_handle_t h;
    nvs_flash_init();
    int32_t r = 0;
    if (nvs_open("records", NVS_READONLY, &h) == ESP_OK) {
        nvs_get_i32(h, RECORD_KEY, &r);
        nvs_close(h);
    }
    return (int)r;
}

String loadHistory() {
    nvs_handle_t h;
    nvs_flash_init();
    String hist = "[]";
    String hkey = String(RECORD_KEY) + "_h";
    if (nvs_open("records", NVS_READONLY, &h) == ESP_OK) {
        size_t len = 0;
        if (nvs_get_str(h, hkey.c_str(), nullptr, &len) == ESP_OK && len > 0) {
            char* buf = new char[len];
            nvs_get_str(h, hkey.c_str(), buf, &len);
            hist = String(buf);
            delete[] buf;
        }
        nvs_close(h);
    }
    return hist;
}

void registerGame(const char* key) {
    nvs_handle_t h;
    nvs_flash_init();
    if (nvs_open("records", NVS_READWRITE, &h) == ESP_OK) {
        char buf[256] = "";
        size_t len = sizeof(buf);
        nvs_get_str(h, "game_list", buf, &len);
        String list = String(buf);
        if (list.indexOf(key) < 0) {
            if (list.length() > 0) list += ",";
            list += key;
            nvs_set_str(h, "game_list", list.c_str());
            nvs_commit(h);
        }
        nvs_close(h);
    }
}

// Guarda sempre a l'historial; actualitza el màxim si cal
// Guarda sempre a l'historial; actualitza el màxim i el comptador
void saveRecord(int score) {
    registerGame(RECORD_KEY);
    nvs_handle_t h;
    nvs_flash_init();
    if (nvs_open("records", NVS_READWRITE, &h) == ESP_OK) {
        int32_t current = 0;
        nvs_get_i32(h, RECORD_KEY, &current);
        if (score > current)
            nvs_set_i32(h, RECORD_KEY, (int32_t)score);

        String hkey = String(RECORD_KEY) + "_h";
        String hist = "[]";
        size_t len = 0;
        if (nvs_get_str(h, hkey.c_str(), nullptr, &len) == ESP_OK && len > 0) {
            char* buf = new char[len];
            nvs_get_str(h, hkey.c_str(), buf, &len);
            hist = String(buf);
            delete[] buf;
        }
        String inner = hist.substring(1, hist.length()-1);
        String nova;
        if (inner.length() == 0) {
            nova = "[" + String(score) + "]";
        } else {
            int count = 1;
            for (int i = 0; i < (int)inner.length(); i++)
                if (inner[i] == ',') count++;
            if (count >= MAX_HISTORY) {
                int lc = inner.lastIndexOf(',');
                inner = (lc >= 0) ? inner.substring(0, lc) : "";
            }
            nova = (inner.length() > 0)
                ? "[" + String(score) + "," + inner + "]"
                : "[" + String(score) + "]";
        }
        nvs_set_str(h, hkey.c_str(), nova.c_str());

        // ── Comptador de partides jugades (clau <joc>_c) ──
        String ckey = String(RECORD_KEY) + "_c";
        int32_t total = 0;
        nvs_get_i32(h, ckey.c_str(), &total);
        nvs_set_i32(h, ckey.c_str(), total + 1);

        nvs_commit(h);
        nvs_close(h);
    }
}
String getAllRecords() {
    if (xSemaphoreTake(recordMutex, pdMS_TO_TICKS(100)) != pdTRUE)
        return "{}";

    nvs_handle_t h;
    nvs_flash_init();
    String json = "{";
    if (nvs_open("records", NVS_READONLY, &h) == ESP_OK) {
        char buf[256] = "";
        size_t len = sizeof(buf);
        nvs_get_str(h, "game_list", buf, &len);
        String list = String(buf);
        bool first = true;
        int start = 0;
        while (start <= (int)list.length()) {
            int comma = list.indexOf(',', start);
            String key = (comma < 0)
                ? list.substring(start)
                : list.substring(start, comma);
            if (key.length() > 0) {
                // Record maxim
                int32_t best = 0;
                nvs_get_i32(h, key.c_str(), &best);
                // Comptador total
                String ckey = key + "_c";
                int32_t total = 0;
                nvs_get_i32(h, ckey.c_str(), &total);
                // Historial
                String hkey = key + "_h";
                String hist = "[]";
                size_t hlen = 0;
                if (nvs_get_str(h, hkey.c_str(), nullptr, &hlen) == ESP_OK && hlen > 0) {
                    char* hbuf = new char[hlen];
                    nvs_get_str(h, hkey.c_str(), hbuf, &hlen);
                    hist = String(hbuf);
                    delete[] hbuf;
                }
                if (!first) json += ",";
                json += "\"" + key + "\":{\"best\":" + String(best) +
                        ",\"total\":" + String(total) +
                        ",\"history\":" + hist + "}";
                first = false;
            }
            if (comma < 0) break;
            start = comma + 1;
        }
        nvs_close(h);
    }
    json += "}";
    xSemaphoreGive(recordMutex);
    return json;
}

// ============================================================
//  DASHBOARD WEB — NO MODIFICAR
// ============================================================
WebServer server(80);

const char PAGE_HTML[] PROGMEM = R"rawhtml(
<!DOCTYPE html>
<html lang="ca">
<head>
<meta charset="UTF-8">
<meta name="viewport" content="width=device-width, initial-scale=1">
<title>ESPectro — Dashboard</title>
<style>
*{box-sizing:border-box;margin:0;padding:0;}
body{background:#0d0d0d;color:#eee;font-family:'Courier New',monospace;
     min-height:100vh;padding:1em;}
h1{color:#ff5000;text-align:center;font-size:1.8em;letter-spacing:4px;
   padding:0.5em 0;border-bottom:2px solid #ff5000;margin-bottom:1em;}
h1 span{color:#fff;}
.grid{display:grid;grid-template-columns:1fr 1fr;gap:1em;max-width:800px;margin:0 auto;}
@media(max-width:600px){.grid{grid-template-columns:1fr;}}
.card{background:#1a1a1a;border:1px solid #333;border-radius:10px;padding:1.2em;}
.card h2{color:#ff5000;font-size:0.9em;letter-spacing:2px;margin-bottom:0.8em;}
.stat{display:flex;justify-content:space-between;align-items:center;
      padding:0.4em 0;border-bottom:1px solid #222;}
.stat:last-child{border:none;}
.stat-label{color:#888;font-size:0.85em;}
.stat-val{color:#0f0;font-weight:bold;font-size:1.1em;}
.stat-val.gold{color:#ffd700;}
.chart{margin-top:0.5em;}
.chart-title{color:#888;font-size:0.75em;margin-bottom:0.5em;}
.bars{display:flex;align-items:flex-end;gap:3px;height:80px;}
.bar-wrap{display:flex;flex-direction:column;align-items:center;flex:1;}
.bar{width:100%;background:#ff5000;border-radius:2px 2px 0 0;min-height:2px;}
.bar-val{color:#888;font-size:0.55em;margin-top:2px;}
input[type=file]{display:none;}
label.btn,button.btn{display:inline-block;padding:0.6em 1.2em;margin:0.3em 0;
  background:#ff5000;color:#fff;border:none;border-radius:6px;
  font-size:0.9em;font-family:monospace;cursor:pointer;width:100%;}
#filename{color:#ff5000;margin:0.4em 0;font-size:0.85em;min-height:1.2em;}
#progress{width:100%;background:#222;border-radius:4px;height:12px;
          margin:0.5em 0;display:none;}
#bar{height:100%;width:0;background:#ff5000;border-radius:4px;transition:width 0.3s;}
#status{min-height:1.5em;font-size:0.85em;color:#ff0;}
.ok{color:#0f0!important;} .err{color:#f44!important;}
</style>
</head>
<body>
<h1><span>ESP</span>ectro — Dashboard</h1>
<div class="grid">
  <div id="games-col">
    <div id="games-container">
      <div class="card"><span style="color:#555">Carregant...</span></div>
    </div>
  </div>
  <div class="card">
    <h2>⬆ Carregar joc</h2>
    <label class="btn" for="file">📂 Triar .bin</label>
    <input type="file" id="file" accept=".bin">
    <div id="filename">Cap arxiu seleccionat</div>
    <button class="btn" onclick="upload()">Pujar joc</button>
    <div id="progress"><div id="bar"></div></div>
    <div id="status"></div>
  </div>
</div>
<script>
function avg(arr){return arr.length?Math.round(arr.reduce((a,b)=>a+b,0)/arr.length):0;}
function renderGame(key,data){
  const hist=data.history||[];
  const best=data.best||0;
  const total=data.total!==undefined?data.total:hist.length;
  const mitjana=avg(hist);
  const darrera=hist[0]||0;
  const last10=hist.slice(0,10).reverse();
  const maxVal=Math.max(...last10,1);
  const bars=last10.length?last10.map(v=>{
    const h=Math.round((v/maxVal)*70);
    return`<div class="bar-wrap"><div class="bar" style="height:${h}px;background:${v===best&&best>0?'#ffd700':'#ff5000'}"></div><div class="bar-val">${v}</div></div>`;
  }).join(''):'<span style="color:#555;font-size:0.8em">Sense dades</span>';
  return`<div class="card" style="margin-bottom:1em">
    <h2>${key.replace(/_/g,' ').toUpperCase()}</h2>
    <div class="stat"><span class="stat-label">Record</span><span class="stat-val gold">${best} pts</span></div>
    <div class="stat"><span class="stat-label">Partides</span><span class="stat-val">${total}</span></div>
    <div class="stat"><span class="stat-label">Mitjana</span><span class="stat-val">${mitjana} pts</span></div>
    <div class="stat"><span class="stat-label">Darrera</span><span class="stat-val ${darrera===best&&best>0?'gold':''}">${darrera} pts</span></div>
    <div class="chart"><div class="chart-title">Ultimes partides</div>
    <div class="bars">${bars}</div></div>
  </div>`;
}
function load(){
  fetch('/records').then(r=>r.json()).then(data=>{
    const entries=Object.entries(data);
    const container=document.getElementById('games-container');
    if(!entries.length){container.innerHTML='<div class="card"><span style="color:#555">Cap joc registrat</span></div>';return;}
    container.innerHTML=entries.map(([k,d])=>renderGame(k,d)).join('');
  }).catch(()=>{});
}
load();
setInterval(load,10000);
const fi=document.getElementById('file');
fi.addEventListener('change',()=>{document.getElementById('filename').textContent=fi.files[0]?.name||'Cap arxiu';});
function upload(){
  const file=fi.files[0];
  const status=document.getElementById('status');
  const bar=document.getElementById('bar');
  const prog=document.getElementById('progress');
  if(!file){status.textContent='Selecciona un arxiu';return;}
  if(!file.name.endsWith('.bin')){status.textContent='Ha de ser .bin';return;}
  const xhr=new XMLHttpRequest();
  xhr.open('POST','/update',true);
  xhr.upload.onprogress=e=>{
    if(e.lengthComputable){const pct=Math.round(e.loaded/e.total*100);prog.style.display='block';bar.style.width=pct+'%';status.textContent='Pujant... '+pct+'%';}
  };
  xhr.onload=()=>{
    if(xhr.status===200){status.textContent='✅ Instal·lat. Reiniciant...';status.className='ok';}
    else{status.textContent='❌ Error: '+xhr.responseText;status.className='err';}
  };
  xhr.onerror=()=>{status.textContent='❌ Error connexió';status.className='err';};
  const fd=new FormData();fd.append('firmware',file,file.name);xhr.send(fd);
}
</script>
</body>
</html>
)rawhtml";

void handleRoot()    { server.send_P(200, "text/html", PAGE_HTML); }
void handleRecords() { server.send(200, "application/json", getAllRecords()); }
void handleUpdate()  {
    server.send(200, "text/plain", Update.hasError() ? "FALLO" : "OK");
    delay(500); ESP.restart();
}
void handleUpdateUpload() {
    HTTPUpload& upload = server.upload();
    if (upload.status == UPLOAD_FILE_START) {
        tft.fillRect(0, 260, 320, 60, TFT_BLACK);
        tft.setTextColor(TFT_YELLOW, TFT_BLACK);
        tft.setTextSize(2);
        tft.setCursor(10, 270);
        tft.print("Rebent firmware...");
        if (!Update.begin(UPDATE_SIZE_UNKNOWN, U_FLASH))
            Update.printError(Serial);
    } else if (upload.status == UPLOAD_FILE_WRITE) {
        if (Update.write(upload.buf, upload.currentSize) != upload.currentSize)
            Update.printError(Serial);
        static size_t total = 0;
        total += upload.currentSize;
        tft.fillRect(10, 300, constrain((int)(total/10000),0,100)*3, 10, TFT_GREEN);
    } else if (upload.status == UPLOAD_FILE_END) {
        if (Update.end(true)) {
            tft.fillRect(0, 260, 320, 60, TFT_BLACK);
            tft.setTextColor(TFT_GREEN, TFT_BLACK);
            tft.setTextSize(2);
            tft.setCursor(10, 270); tft.print("Joc instal·lat!");
            tft.setCursor(10, 295); tft.print("Reiniciant...");
        } else { Update.printError(Serial); }
    }
}


// ============================================================
//  HANDLERS MCP — NO MODIFICAR
// ============================================================
void handleMcpTools() {
    String json = "{\"tools\":["
        "{\"name\":\"get_records\","
        "\"description\":\"Records i historial de puntuacions\","
        "\"inputSchema\":{\"type\":\"object\",\"properties\":{}}},"
        "{\"name\":\"get_status\","
        "\"description\":\"Estat de la consola: uptime i memoria\","
        "\"inputSchema\":{\"type\":\"object\",\"properties\":{}}},"
        "{\"name\":\"get_system_info\","
        "\"description\":\"Info hardware: CPU, flash, PSRAM\","
        "\"inputSchema\":{\"type\":\"object\",\"properties\":{}}}"
        "]}";
    server.sendHeader("Access-Control-Allow-Origin", "*");
    server.send(200, "application/json", json);
}

void handleMcpGetRecords() {
    String records = getAllRecords();
    String resp = "{\"content\":[{\"type\":\"text\",\"text\":" + records + "}]}";
    server.sendHeader("Access-Control-Allow-Origin", "*");
    server.send(200, "application/json", resp);
}

void handleMcpGetStatus() {
    unsigned long uptime = millis() / 1000;
    String resp = "{\"content\":[{\"type\":\"text\",\"text\":{"
                  "\"uptime_s\":" + String(uptime) + ","
                  "\"free_heap_bytes\":" + String(ESP.getFreeHeap()) + ","
                  "\"wifi_ssid\":\"ESPectro\","
                  "\"ip\":\"192.168.4.1\","
                  "\"version\":\"1.0.0\"}}]}";
    server.sendHeader("Access-Control-Allow-Origin", "*");
    server.send(200, "application/json", resp);
}

void handleMcpGetSystemInfo() {
    String resp = "{\"content\":[{\"type\":\"text\",\"text\":{"
                  "\"chip\":\"ESP32-S3\","
                  "\"cpu_freq_mhz\":" + String(ESP.getCpuFreqMHz()) + ","
                  "\"flash_size_mb\":" + String(ESP.getFlashChipSize()/1024/1024) + ","
                  "\"free_heap_bytes\":" + String(ESP.getFreeHeap()) + ","
                  "\"free_psram_bytes\":" + String(ESP.getFreePsram()) + ","
                  "\"sdk_version\":\"" + String(ESP.getSdkVersion()) + "\"}}]}";
    server.sendHeader("Access-Control-Allow-Origin", "*");
    server.send(200, "application/json", resp);
}

void handleMcpCall() {
    String tool = server.arg("tool");
    if      (tool == "get_records")     handleMcpGetRecords();
    else if (tool == "get_status")      handleMcpGetStatus();
    else if (tool == "get_system_info") handleMcpGetSystemInfo();
    else {
        String err = "{\"error\":\"Tool no trobada: " + tool + "\"}";
        server.send(404, "application/json", err);
    }
}
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
void loop() {
    tft.fillScreen(TFT_BLACK);
    int best = loadRecord();
    drawMenu(best);

    while (true) {
        if (digitalRead(BTN_A_PIN) == LOW) {
            delay(50);
            runGame();
            break;
        }
        if (digitalRead(BTN_B_PIN) == LOW) {
            delay(50);
            runGameLoader();
            break;
        }
        delay(20);
    }
}

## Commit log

2026-05-30 partitions ota ja no es necessari
    [partitions_ota.csv]
2026-05-30 añadir wifi task freertos i dashbaord de records http server
2026-05-30 añadir mcp a la base
2026-05-30 añadir archivos 3D y actualizar el readme
    [back.stl, front.stl]
2026-05-30 limpieza de repo
2026-05-31 añadir wifi status a la plantilla
2026-05-31 arreglar plantilla afegir grafic dactualitzacio
    [main.cpp]
